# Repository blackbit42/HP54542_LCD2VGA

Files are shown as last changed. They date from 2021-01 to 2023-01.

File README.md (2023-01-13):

# Conversion of HP 54520C / 54540C oscilloscopes to VGA display(s)

The HP 54520C / 54540C series of oscilloscopes is equipped with color LCD displays, in contrast to their non-C predecessors which had monochrome CRT displays. While the multi-color display is nice in principle, the LCDs that were used unfortunately commonly failed. Those scopes are still quite capable by 2023 standards, hence worth preserving. The content of this repository is a conversion of the scope to VGA through a FPGA bitstream and a PCB design that is using an [UPduino](https://tinyvision.ai/products/upduino-v3-1) as a daughterboard.

Pretty much the same hack has been done before by [Adil Malik](https://hackaday.com/2017/06/01/fpga-rescues-scope-from-the-dumpster/), though now FPGA and PCB designs are made available for other people to reproduce.

# Implementation details

The PCB is designed to have mounting holes placed in distance to be compatible with [VESA MIS-D (75x75)](https://en.wikipedia.org/wiki/Flat_Display_Mounting_Interface), which allows the PCB to be mounted sturdily at the backside of the used VGA TFT inside the scope.

Hirose DF13 connectors are stipulated on the PCB so that the original LCD cables don't have to be modified.

The PCB and UPduino are powered from the LCD connections. The VGA TFT is powered from the scope PSU.

The entire modification of the instrument is non-invasive and can be undone if desired.

## Findings

HP decided to mount the LCD panel upside down. Probably as that was convenient is regards to the position of the connectors. An implication of that is that the internal VGGA monitor is mounted upside down as well (which doesn't make a difference really) and that an external monitor must be rotated as well. If one would desire to change that, a frame buffer must be implemented in the FPGA, which isn't hard to do but required more RAM than the UPduino has.

## Errata

Rev.1 of the PCB design contains an error. The footprint for the UPduino is 0.2" too narrow. I fixed this with infamous offset-pinheaders of shame. Keep this in mind if you intend to get a PCB produced. Patches welcome :-)

## PCBs

As of 10 Jan 2023 I have some spare PCBs in stock. Get in touch via the email address I've used for the commits if you want one.

## Pictures

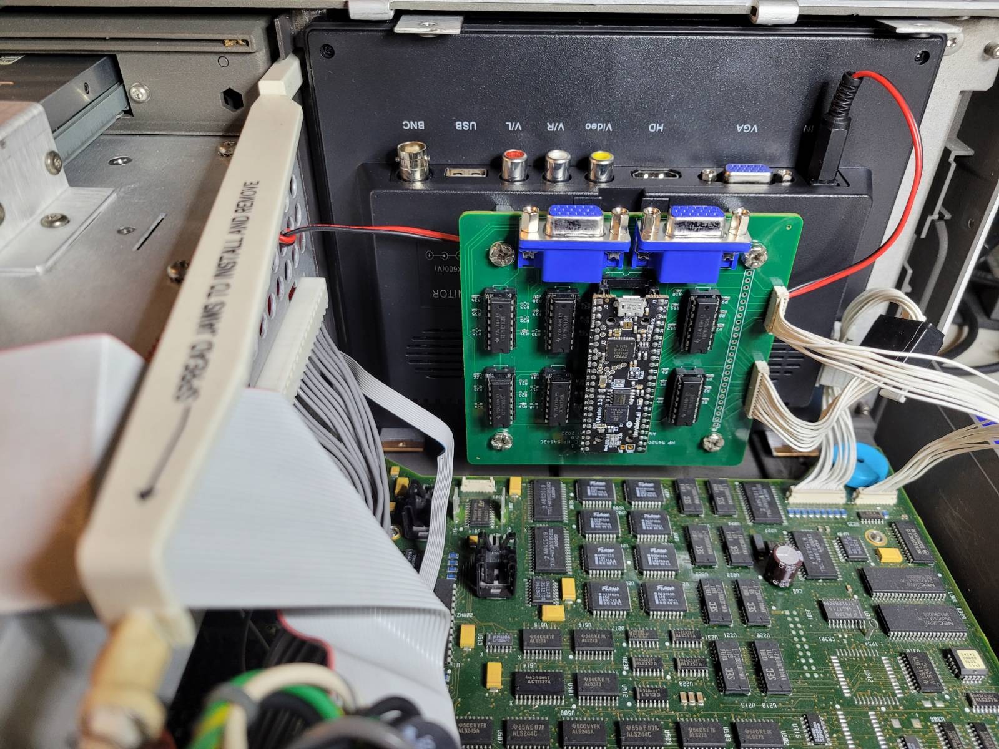
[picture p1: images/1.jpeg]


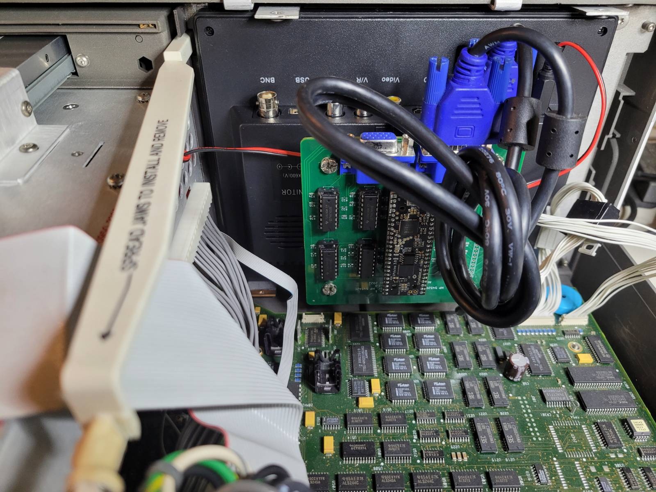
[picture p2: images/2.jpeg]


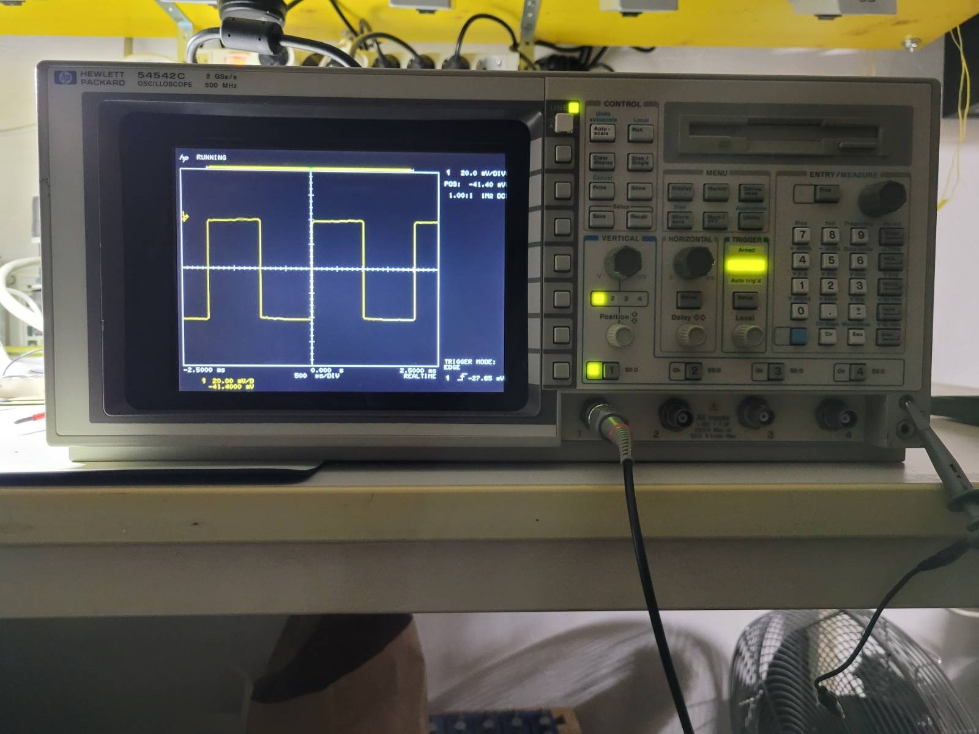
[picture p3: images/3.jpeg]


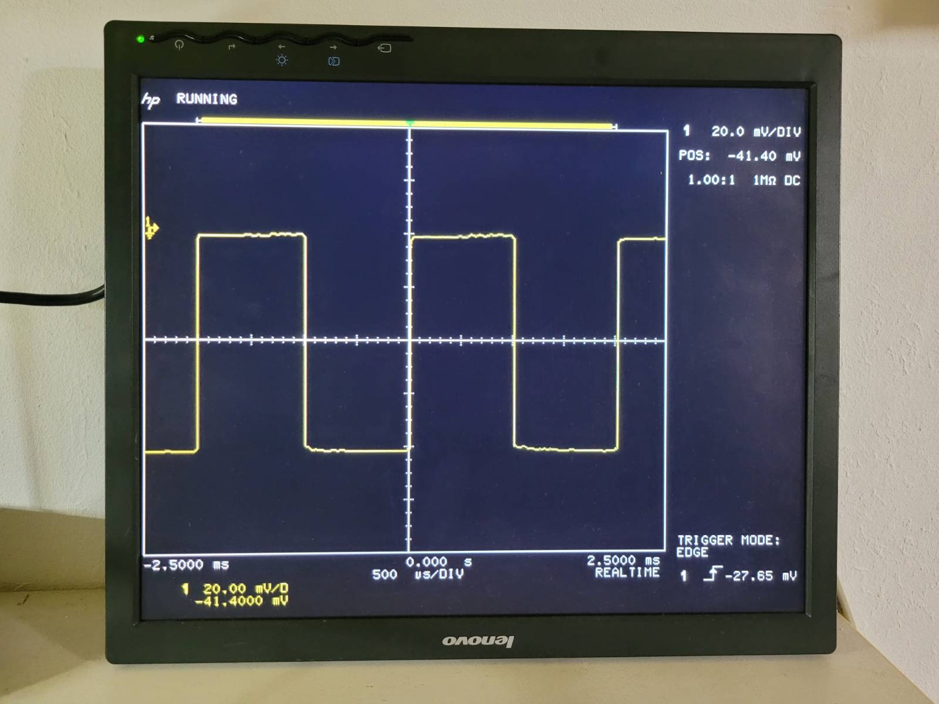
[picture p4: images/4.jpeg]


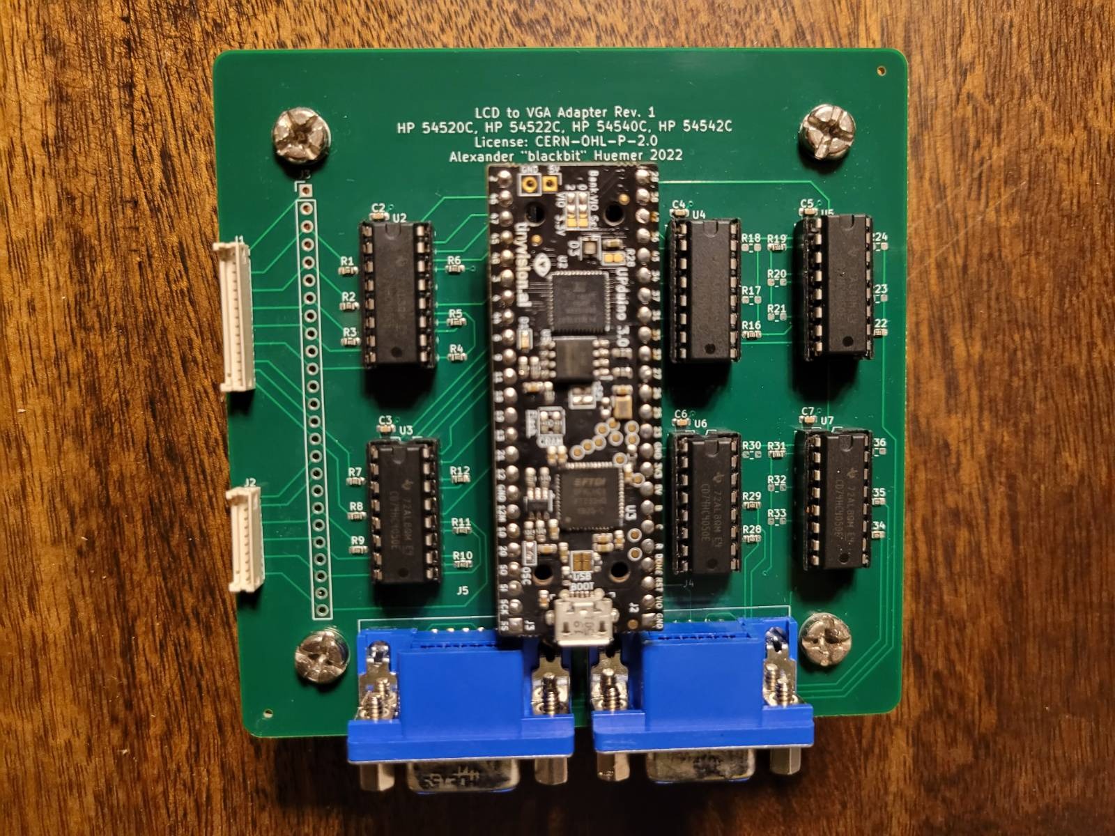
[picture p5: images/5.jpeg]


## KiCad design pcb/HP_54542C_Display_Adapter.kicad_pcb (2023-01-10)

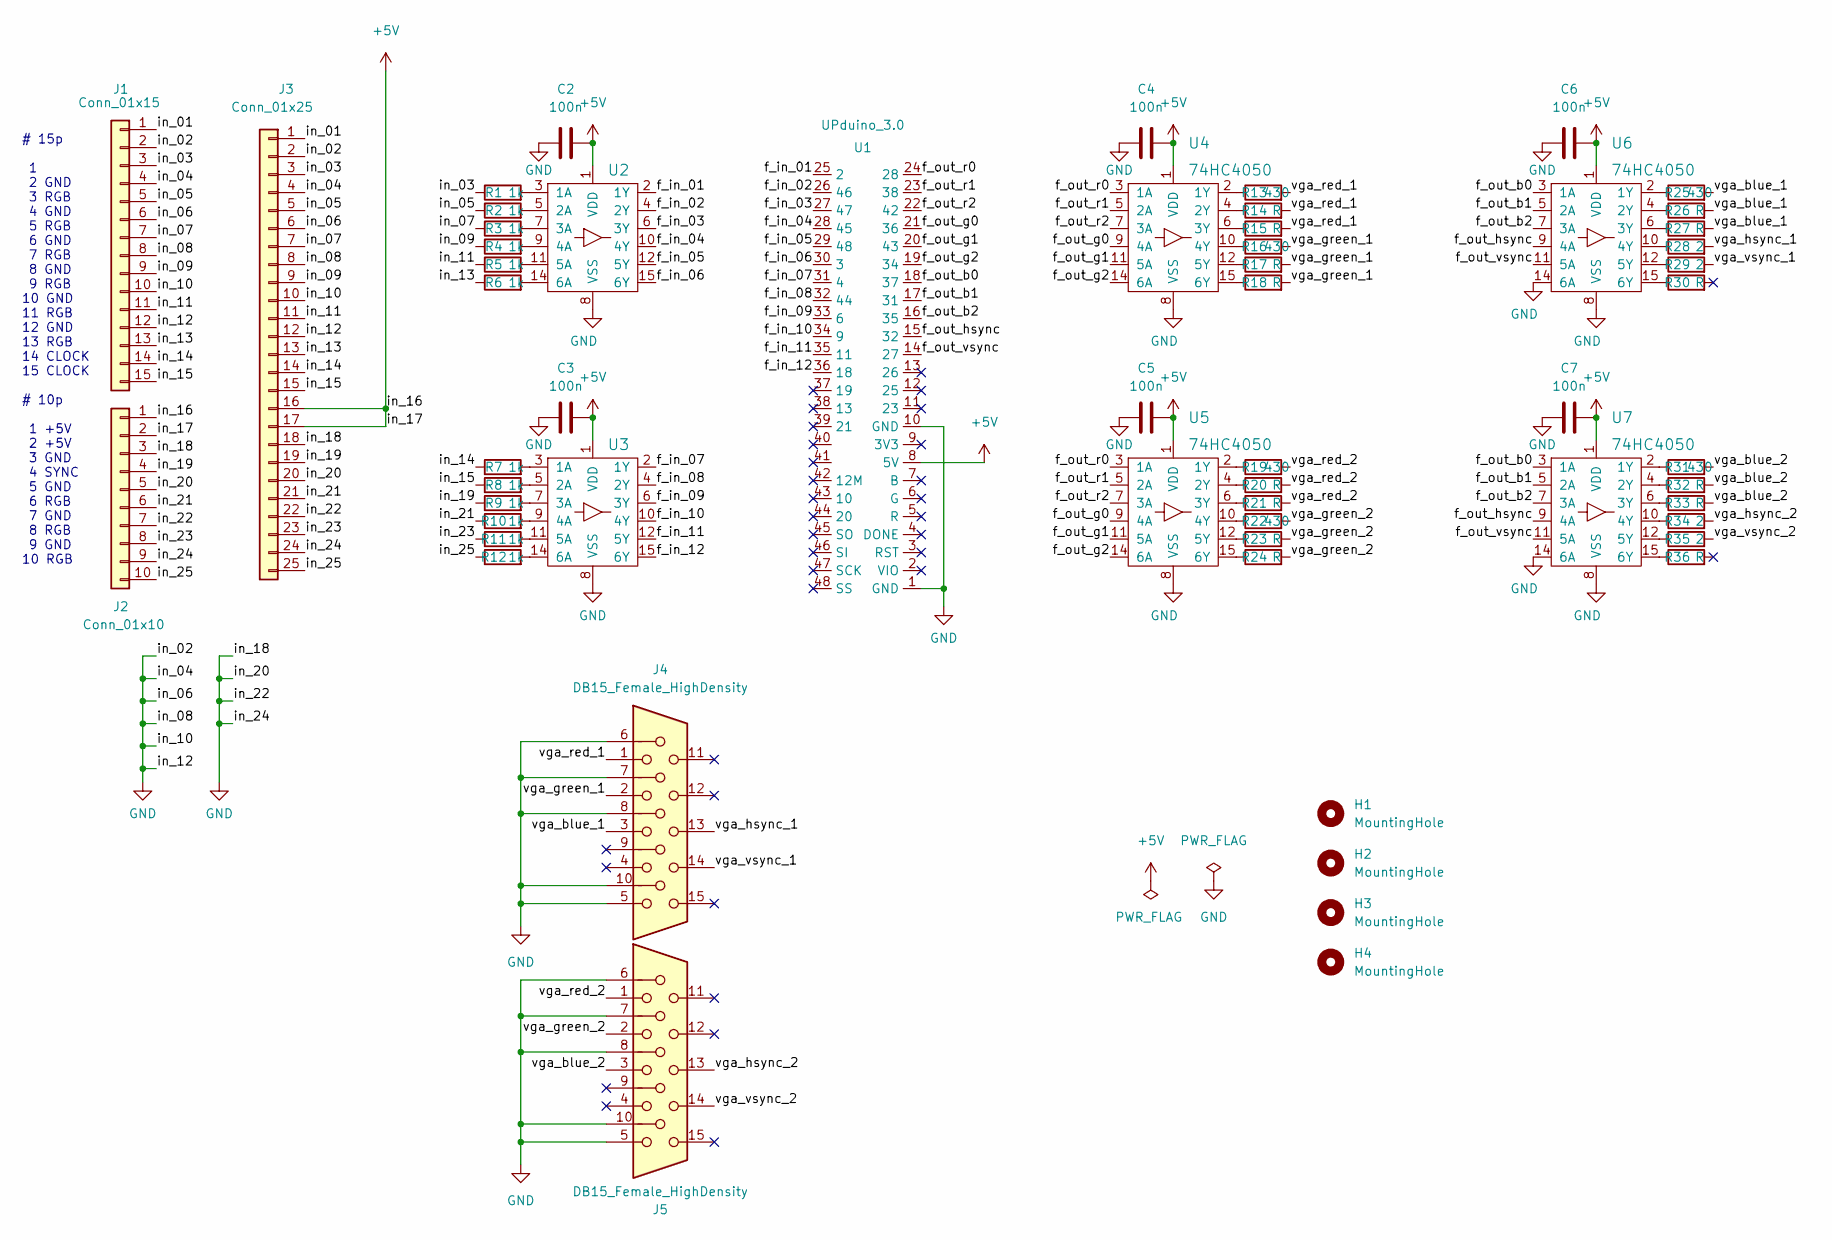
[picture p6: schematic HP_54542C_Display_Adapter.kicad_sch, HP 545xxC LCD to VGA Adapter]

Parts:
C2, C3, C4, C5, C6, C7: 100n; C_0603_1608Metric_Pad1.08x0.95mm_HandSolder; LCSC C14663
H1, H2, H3, H4: MountingHole; MountingHole_4.3mm_M4_DIN965_Pad
J1: Conn_01x15; PinSocket_1x15_P1.27mm_Vertical
J2: Conn_01x10; PinSocket_1x10_P1.27mm_Vertical
J3: Conn_01x25; PinHeader_1x25_P2.54mm_Vertical
J4, J5: DB15_Female_HighDensity; VGA
R1, R2, R3, R4, R5, R6, R7, R8, R9, R10, R11, R12: 1k; R_0603_1608Metric_Pad0.98x0.95mm_HandSolder; LCSC C21190
R13, R16, R19, R22, R25, R31: 430; R_0603_1608Metric_Pad0.98x0.95mm_HandSolder; LCSC C23170
R14, R15, R17, R18, R20, R21, R23, R24, R26, R27, R30, R32, R33, R36: R; R_0603_1608Metric_Pad0.98x0.95mm_HandSolder
R28, R29, R34, R35: 2; R_0603_1608Metric_Pad0.98x0.95mm_HandSolder; LCSC C22977
U1: UPduino_3.0; DIP-48_W15.24mm_LongPads
U2, U3, U4, U5, U6, U7: 74HC4050; DIP-16_W7.62mm_LongPads

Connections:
+5V: C2.2, C3.2, C4.2, C5.2, C6.2, C7.2, J2.1, J2.2, J3.16, J3.17, U1.8 (5V), U2.1 (VDD), U3.1 (VDD), U4.1 (VDD), U5.1 (VDD), U6.1 (VDD), U7.1 (VDD)
/f_in_01: U1.25 (2), U2.2 (1Y)
/f_in_02: U1.26 (46), U2.4 (2Y)
/f_in_03: U1.27 (47), U2.6 (3Y)
/f_in_04: U1.28 (45), U2.10 (4Y)
/f_in_05: U1.29 (48), U2.12 (5Y)
/f_in_06: U1.30 (3), U2.15 (6Y)
/f_in_07: U1.31 (4), U3.2 (1Y)
/f_in_08: U1.32 (44), U3.4 (2Y)
/f_in_09: U1.33 (6), U3.6 (3Y)
/f_in_10: U1.34 (9), U3.10 (4Y)
/f_in_11: U1.35 (11), U3.12 (5Y)
/f_in_12: U1.36 (18), U3.15 (6Y)
/f_out_b0: U1.18 (37), U6.3 (1A), U7.3 (1A)
/f_out_b1: U1.17 (31), U6.5 (2A), U7.5 (2A)
/f_out_b2: U1.16 (35), U6.7 (3A), U7.7 (3A)
/f_out_g0: U1.21 (36), U4.9 (4A), U5.9 (4A)
/f_out_g1: U1.20 (43), U4.11 (5A), U5.11 (5A)
/f_out_g2: U1.19 (34), U4.14 (6A), U5.14 (6A)
/f_out_hsync: U1.15 (32), U6.9 (4A), U7.9 (4A)
/f_out_r0: U1.24 (28), U4.3 (1A), U5.3 (1A)
/f_out_r1: U1.23 (38), U4.5 (2A), U5.5 (2A)
/f_out_r2: U1.22 (42), U4.7 (3A), U5.7 (3A)
/f_out_vsync: U1.14 (27), U6.11 (5A), U7.11 (5A)
/in_01: J1.1, J3.1
/in_03: J1.3, J3.3, R1.1
/in_05: J1.5, J3.5, R2.1
/in_07: J1.7, J3.7, R3.1
/in_09: J1.9, J3.9, R4.1
/in_11: J1.11, J3.11, R5.1
/in_13: J1.13, J3.13, R6.1
/in_14: J1.14, J3.14, R7.1
/in_15: J1.15, J3.15, R8.1
/in_19: J2.4, J3.19, R9.1
/in_21: J2.6, J3.21, R10.1
/in_23: J2.8, J3.23, R11.1
/in_25: J2.10, J3.25, R12.1
/vga_blue_1: J4.3, R25.2, R26.2, R27.2
/vga_blue_2: J5.3, R31.2, R32.2, R33.2
/vga_green_1: J4.2, R16.2, R17.2, R18.2
/vga_green_2: J5.2, R22.2, R23.2, R24.2
/vga_hsync_1: J4.13, R28.2
/vga_hsync_2: J5.13, R34.2
/vga_red_1: J4.1, R13.2, R14.2, R15.2
/vga_red_2: J5.1, R19.2, R20.2, R21.2
/vga_vsync_1: J4.14, R29.2
/vga_vsync_2: J5.14, R35.2
GND: C2.1, C3.1, C4.1, C5.1, C6.1, C7.1, J1.2, J1.4, J1.6, J1.8, J1.10, J1.12, J2.3, J2.5, J2.7, J2.9, J3.2, J3.4, J3.6, J3.8, J3.10, J3.12, J3.18, J3.20, J3.22, J3.24, J4.5, J4.6, J4.7, J4.8, J4.10, J5.5, J5.6, J5.7, J5.8, J5.10, U1.1 (GND), U1.10 (GND), U2.8 (VSS), U3.8 (VSS), U4.8 (VSS), U5.8 (VSS), U6.8 (VSS), U6.14 (6A), U7.8 (VSS), U7.14 (6A)
unnamed: R1.2, U2.3 (1A)
unnamed: R2.2, U2.5 (2A)
unnamed: R3.2, U2.7 (3A)
unnamed: R4.2, U2.9 (4A)
unnamed: R5.2, U2.11 (5A)
unnamed: R6.2, U2.14 (6A)
unnamed: R7.2, U3.3 (1A)
unnamed: R8.2, U3.5 (2A)
unnamed: R9.2, U3.7 (3A)
unnamed: R10.2, U3.9 (4A)
unnamed: R11.2, U3.11 (5A)
unnamed: R12.2, U3.14 (6A)
unnamed: R13.1, U4.2 (1Y)
unnamed: R14.1, U4.4 (2Y)
unnamed: R15.1, U4.6 (3Y)
unnamed: R16.1, U4.10 (4Y)
unnamed: R17.1, U4.12 (5Y)
unnamed: R18.1, U4.15 (6Y)
unnamed: R19.1, U5.2 (1Y)
unnamed: R20.1, U5.4 (2Y)
unnamed: R21.1, U5.6 (3Y)
unnamed: R22.1, U5.10 (4Y)
unnamed: R23.1, U5.12 (5Y)
unnamed: R24.1, U5.15 (6Y)
unnamed: R25.1, U6.2 (1Y)
unnamed: R26.1, U6.4 (2Y)
unnamed: R27.1, U6.6 (3Y)
unnamed: R28.1, U6.10 (4Y)
unnamed: R29.1, U6.12 (5Y)
unnamed: R30.1, U6.15 (6Y)
unnamed: R31.1, U7.2 (1Y)
unnamed: R32.1, U7.4 (2Y)
unnamed: R33.1, U7.6 (3Y)
unnamed: R34.1, U7.10 (4Y)
unnamed: R35.1, U7.12 (5Y)
unnamed: R36.1, U7.15 (6Y)

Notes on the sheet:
# 15p 1 2 GND 3 RGB 4 GND 5 RGB 6 GND 7 RGB 8 GND 9 RGB 10 GND 11 RGB 12 GND 13 RGB 14 CLOCK 15 CLOCK # 10p 1 +5V 2 +5V 3 GND 4 SYNC 5 GND 6 RGB 7 GND 8 RGB 9 GND 10 RGB

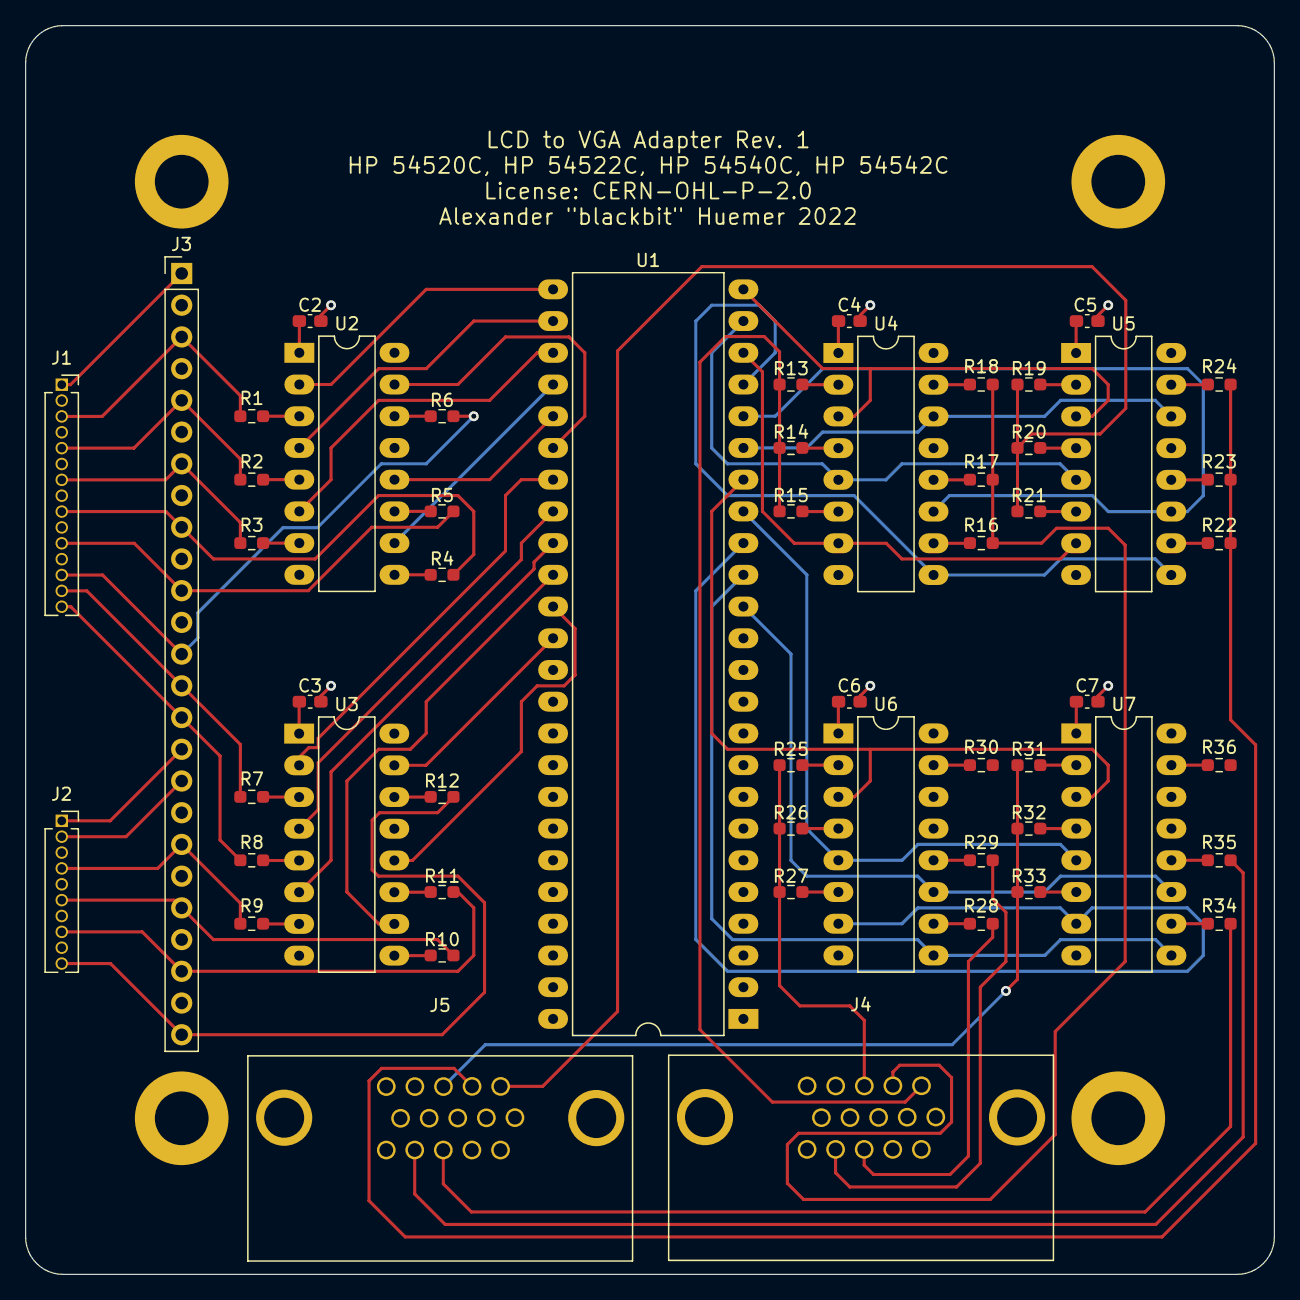
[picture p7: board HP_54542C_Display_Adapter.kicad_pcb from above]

Board: 4 copper layers, 100.0 x 100.0 mm, 58 parts (0 on the bottom side), 84 nets.

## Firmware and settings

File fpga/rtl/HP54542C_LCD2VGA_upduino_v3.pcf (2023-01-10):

# Pin-mapping for UPDuino V3

set_io --warn-no-port iw_r0 2
#set_io --warn-no-port iw_r1
#set_io --warn-no-port iw_r2

set_io --warn-no-port iw_g0 45
#set_io --warn-no-port iw_g1
#set_io --warn-no-port iw_g2

set_io --warn-no-port iw_b0 9
#set_io --warn-no-port iw_b1
#set_io --warn-no-port iw_b2

set_io --warn-no-port iw_clk 44
set_io --warn-no-port iw_sync 6

set_io --warn-no-port ow_r0 28
#set_io --warn-no-port ow_r1
#set_io --warn-no-port ow_r2

set_io --warn-no-port ow_g0 36
#set_io --warn-no-port ow_g1
#set_io --warn-no-port ow_g2

set_io --warn-no-port ow_b0 37
#set_io --warn-no-port ow_b1
#set_io --warn-no-port ow_b2

set_io --warn-no-port ow_hsync 32
set_io --warn-no-port ow_vsync 27

#set_io --warn-no-port D_up 99
#set_io --warn-no-port D_right 98
#set_io --warn-no-port D_down 97
#set_io --warn-no-port D_left 96
#set_io --warn-no-port D_center 95

set_io --warn-no-port led_r 41
set_io --warn-no-port led_g 40
set_io --warn-no-port led_b 39

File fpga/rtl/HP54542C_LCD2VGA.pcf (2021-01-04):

# Pin-mapping is for ICEstick

set_io --warn-no-port iw_clk 119
set_io --warn-no-port iw_sync 118
set_io --warn-no-port iw_r0 117
#set_io --warn-no-port iw_r1 116
#set_io --warn-no-port iw_r2 115
set_io --warn-no-port iw_g0 116
#set_io --warn-no-port iw_g1 113
#set_io --warn-no-port iw_g2 112
set_io --warn-no-port iw_b0 115
#set_io --warn-no-port iw_b1 98
#set_io --warn-no-port iw_b2 97
#set_io --warn-no-port ow_hsync 96
#set_io --warn-no-port ow_vsync 95
set_io --warn-no-port ow_r0 44
#set_io --warn-no-port ow_r1 93
#set_io --warn-no-port ow_r2 92
set_io --warn-no-port ow_g0 45
#set_io --warn-no-port ow_g1 90
#set_io --warn-no-port ow_g2 89
set_io --warn-no-port ow_b0 47
#set_io --warn-no-port ow_b1 87
#set_io --warn-no-port ow_b2 86
set_io --warn-no-port ow_hsync 48
set_io --warn-no-port ow_vsync 56

set_io --warn-no-port D_up 99
set_io --warn-no-port D_right 98
set_io --warn-no-port D_down 97
set_io --warn-no-port D_left 96
set_io --warn-no-port D_center 95

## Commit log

2021-01-01 add output wires for [hv]sync and adjust .pcf
2021-01-02 turn all LEDs off
2023-01-10 add kicad design
    [HP_54542C_Display_Adapter-B_Cu.gbl, HP_54542C_Display_Adapter-B_Mask.gbs, HP_54542C_Display_Adapter-B_Paste.gbp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]

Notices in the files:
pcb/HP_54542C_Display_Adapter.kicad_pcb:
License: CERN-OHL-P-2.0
